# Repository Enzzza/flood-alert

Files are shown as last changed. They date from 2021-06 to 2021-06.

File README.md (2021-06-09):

## _Flood detection system_
 
Last winter we almost had a problem when the autumn leaves clogged the drain, luckily I reacted on time. That's why i decided to build flood alert system that would notify me over WiFi if there is flood detection.

Parts needed: 

- Esp32 Microcontroller 
- PP Float Switch
- Active Buzzer
- Leds
- 220Ω Resistors
- Cables
<br>
<br>

<br>

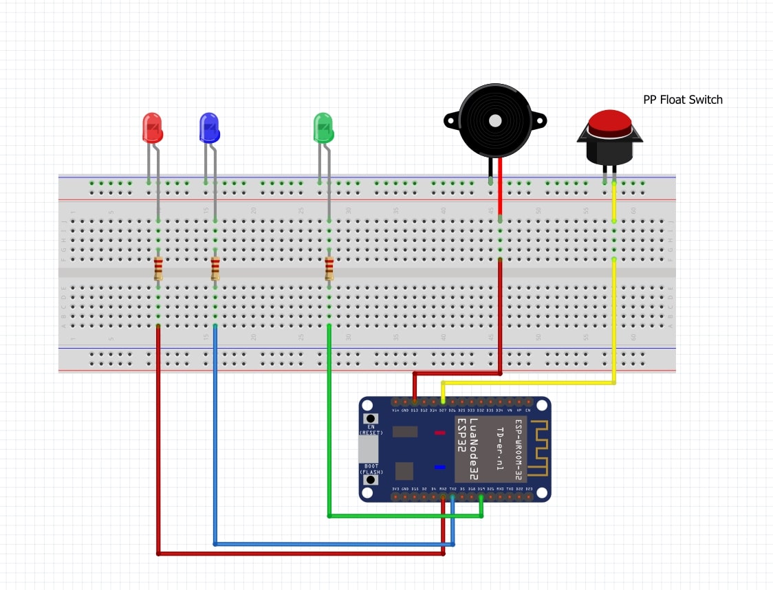
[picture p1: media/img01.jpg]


<p align = "left">
Basic schematic diagram
</p>

Idea behind this system is when PP Float Switch detect water rising it sends HIGH signal to ESP32 microcontroller. After ESP32 detects this signal it will send push notification over WiFi to the Blynk server, Blynk server will send notification to our device. Also ESP32 will play alarm sound  and it will turn on led lights. When ESP32 is not detecting flood it will indicate that with green led light.

<br>

Next step is to build prototype.
<br>

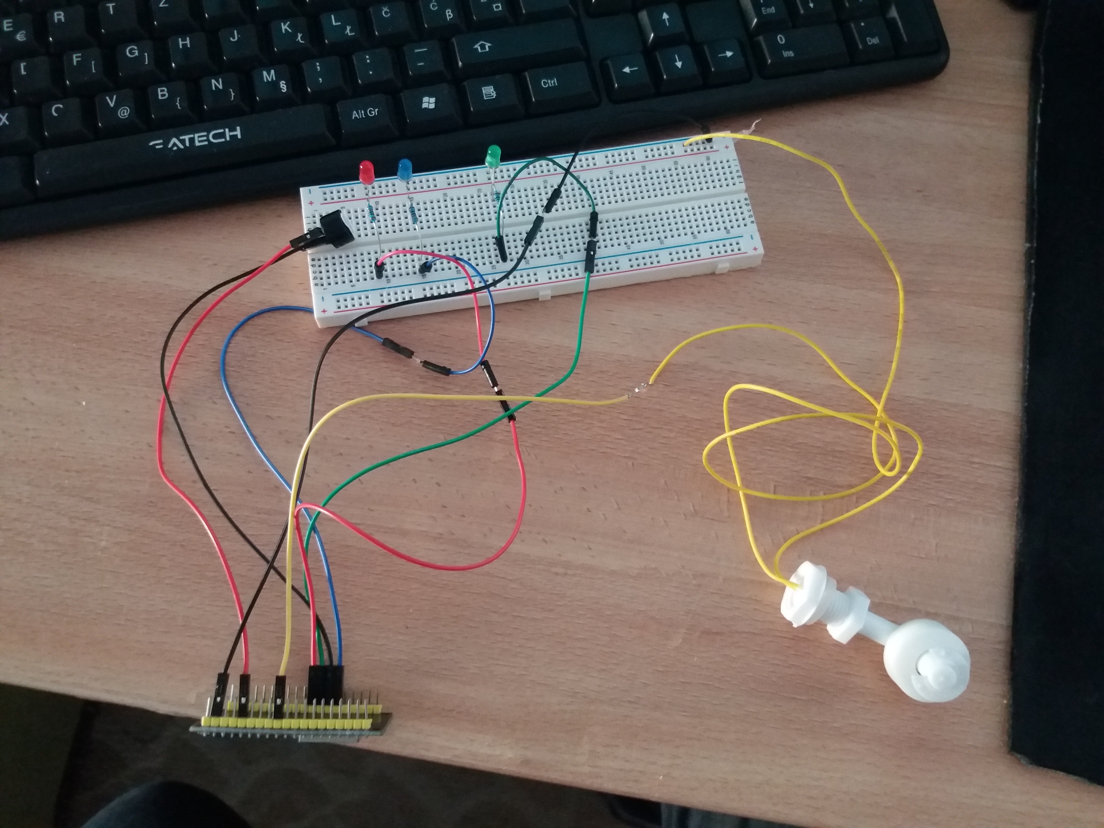
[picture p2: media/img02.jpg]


<p align = "left">
Prototype
</p>

<br>

Now we will put it all together. I will use IP55 enclosure box because this box won't be directly exposed to the rain. If your box will be exposed to rain use IP66, IP67 or IP68 type.

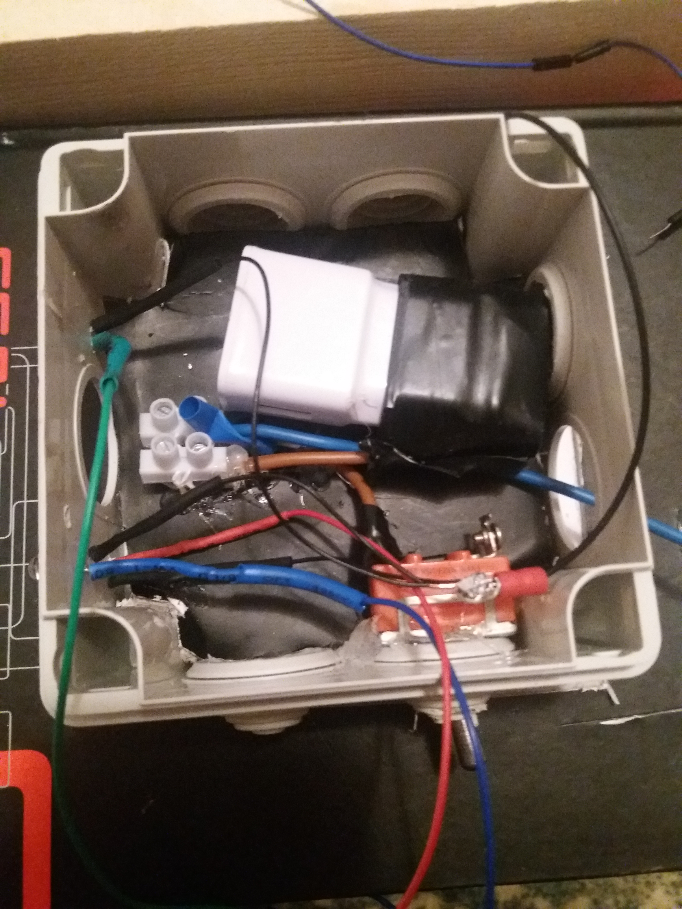
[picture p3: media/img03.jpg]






<br>
<br>

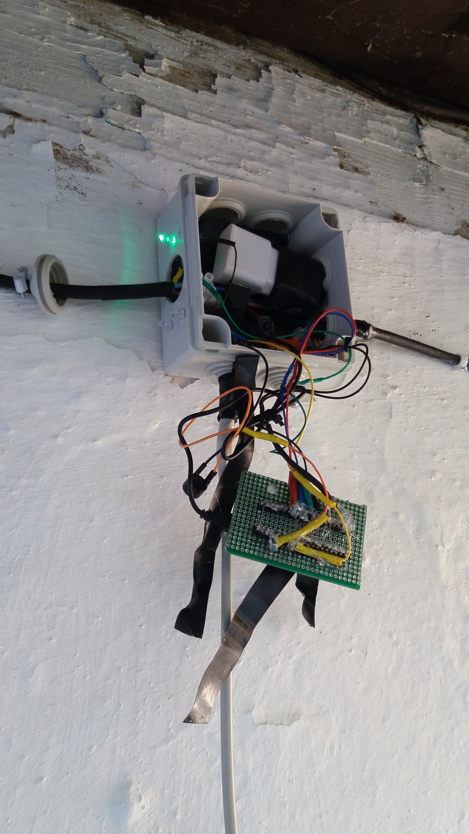
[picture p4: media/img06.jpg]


<p align = "left">
Mounting box on the wall
</p>



<p align = "left">
Mounting sensor to the bracket
</p>

After we finished hardware part of project now is time to setup [Blynk](https://docs.blynk.cc/) server.

Download Blynk App for your smartphone.

1. Create a Blynk Account
After you download the Blynk App, you’ll need to create a New Blynk account. This account is separate from the accounts used for the Blynk Forums, in case you already have one.

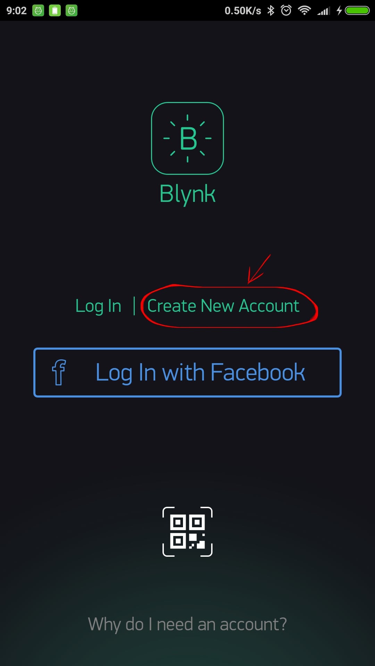
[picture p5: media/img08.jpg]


2. Create a New Project
After you’ve successfully logged into your account, start by creating a new project.

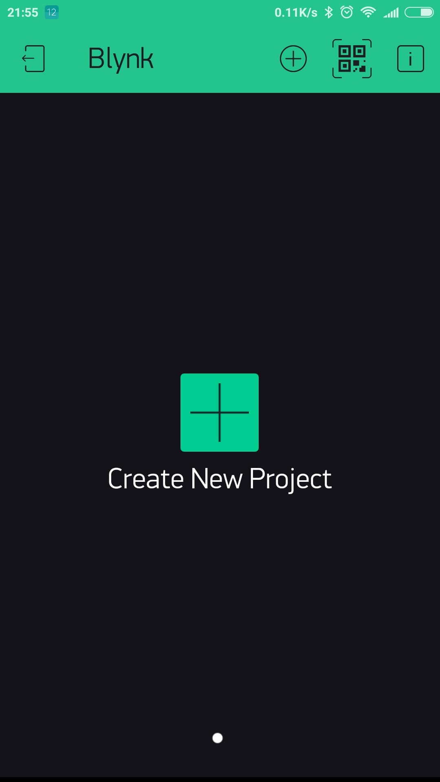
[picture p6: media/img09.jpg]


3. Choose Your Hardware
We will use Esp32

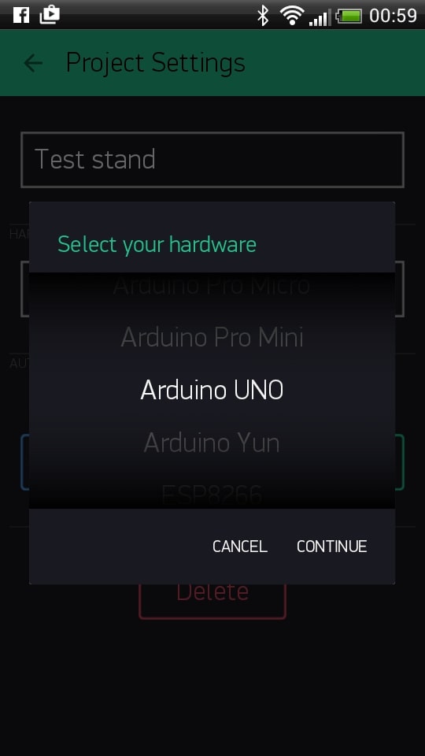
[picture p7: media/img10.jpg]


4. Auth Token
Auth Token is a unique identifier which is needed to connect your hardware to your smartphone. Every new project you create will have its own Auth Token. You’ll get Auth Token automatically on your email after project creation. You can also copy it manually. Click on devices section and selected required device :

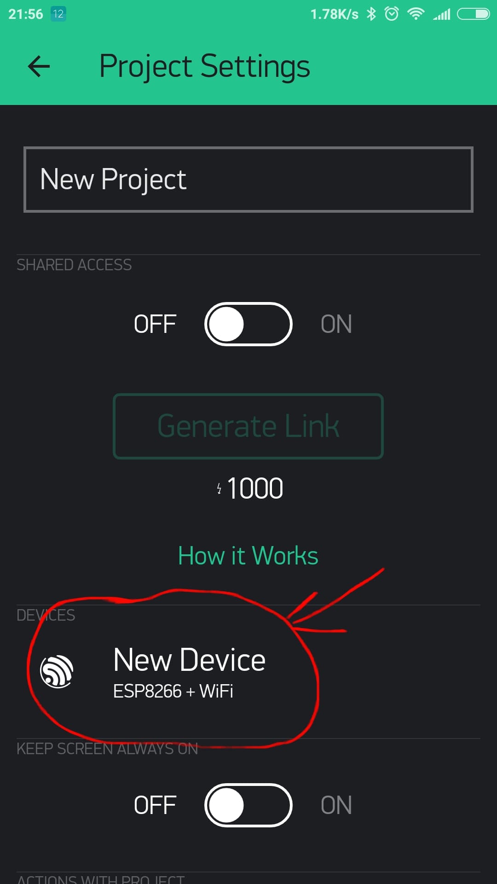
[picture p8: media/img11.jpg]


And you’ll see token :

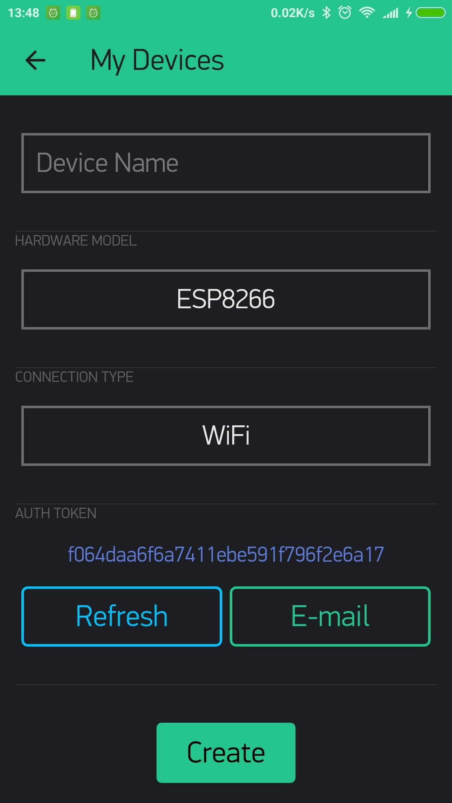
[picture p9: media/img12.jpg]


NOTE: Don’t share your Auth Token with anyone, unless you want someone to have access to your hardware.

Now press the “Create” button.

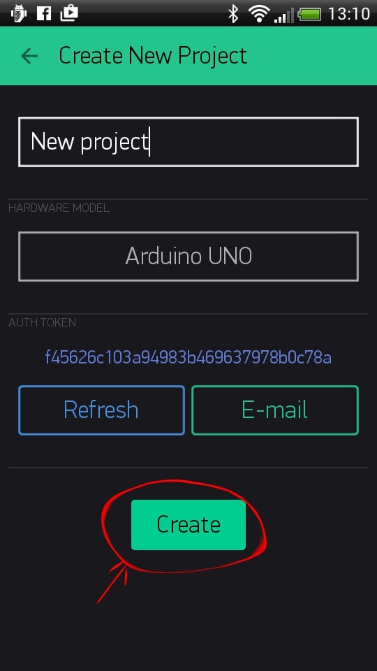
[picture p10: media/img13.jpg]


5. Add a Widget

We will use notification widget

Push Notification widget allows you to send push notification from your hardware to your device.
<br>
<br>
Example code:

```powershell
Blynk.notify("Hey, Blynkers! My hardware can push now!");
```

In esp32 folder there is config.h file copy token you got from step 4 into this file.

```powershell
char ssid[]            = "YOUR SSID";
char pass[]            = "YOUR PASSWORD";
char auth[]            = "YOUR BLYNK AUTH TOKEN";
char serveraddr[]      = "blynk-cloud.com";
unsigned int port      = 80;

// Uncomment this if you are hosting your blynk server  locally
//IPAddress serveraddr  (192,   168,   0,   55); // local server ip 
//unsigned int port      = 1234; // port of your local server

// Static IP
IPAddress esp32_ip ( 192,  168,   0,  100);
IPAddress gateway_ip ( 192,  168,   0,   1);
IPAddress subnet_mask(255, 255, 255,     0);
IPAddress primary_DNS(8, 8, 8, 8);   //optional
IPAddress secondary_DNS(8, 8, 4, 4); //optional

```

Now we can recive push notifications on our smartphone.

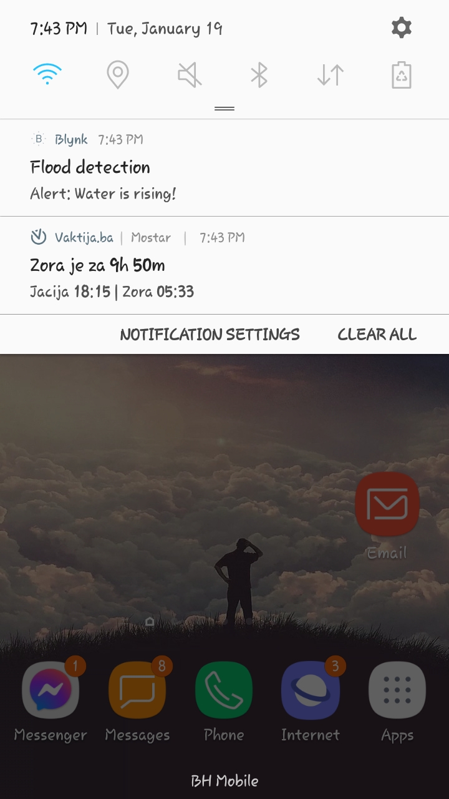
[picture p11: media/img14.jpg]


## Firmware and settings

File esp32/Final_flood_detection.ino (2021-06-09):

#define RED_PIN 16
#define GREEN_LED 19
#define BLUE_PIN 17
#define BUZZER_PIN 13
#define FLOAT_PIN 27

#define ESP32_HOSTNAME "FloodDetectionAlarm"
#define BLYNK_TIMEOUT_MS  500
#define BLYNK_HEARTBEAT   17
#define BLYNK_PRINT Serial
#include <WiFi.h>
#include <BlynkSimpleEsp32.h>
#include "config.h"

bool isDeviceOnline = false;

class Flasher
{
    // Class Member Variables
    // These are initialized at startup
    int ledPin;      // the number of the LED pin
    long OnTime;     // milliseconds of on-time
    long OffTime;    // milliseconds of off-time

    // These maintain the current state
    int ledState;                 // ledState used to set the LED
    unsigned long previousMillis;   // will store last time LED was updated

    // Constructor - creates a Flasher
    // and initializes the member variables and state
  public:
    Flasher(int pin, long on, long off)
    {
      ledPin = pin;
      pinMode(ledPin, OUTPUT);

      OnTime = on;
      OffTime = off;

      ledState = LOW;
      previousMillis = 0;
    }

    void Update()
    {
      // check to see if it's time to change the state of the LED
      unsigned long currentMillis = millis();

      if ((ledState == HIGH) && (currentMillis - previousMillis >= OnTime))
      {
        ledState = LOW;  // Turn it off
        previousMillis = currentMillis;  // Remember the time
        digitalWrite(ledPin, ledState);  // Update the actual LED
      }
      else if ((ledState == LOW) && (currentMillis - previousMillis >= OffTime))
      {
        ledState = HIGH;  // turn it on
        previousMillis = currentMillis;   // Remember the time
        digitalWrite(ledPin, ledState);   // Update the actual LED
      }
    }

    void setOnTime(int on) {
      OnTime = on;
    }

    void setOffTime(int off) {
      OffTime = off;
    }

    void Stop() {
      digitalWrite(ledPin, LOW);
    }
};

class Alarm
{
    Flasher _redLed;
    Flasher _blueLed;


    int _redPin;
    int _bluePin;
    int _buzzerPin;


    static const int _maxNumOfEvents{10};
    static const int _delayTime{10};

    int _sentEvents;
    unsigned long _timeOfLastSentEvent;


    int _buzzerFreq;
    const static int _buzzerChannel {0};
    const static int _buzzerResolution {8};


  public:


    Alarm(int redPin, int bluePin, int buzzerPin):
      _redLed(redPin, 200, 200),
      _blueLed(bluePin, 400, 400){


      _buzzerPin = buzzerPin;
      _redPin = redPin;
      _bluePin = bluePin;

      _sentEvents = 0;
      _timeOfLastSentEvent = 0;

      _buzzerFreq = 2000;
      ledcSetup(_buzzerChannel, _buzzerFreq, _buzzerResolution);
      ledcAttachPin(_buzzerPin, _buzzerChannel);

    }

    void turnOnLeds() {
      _redLed.Update();
      _blueLed.Update();
    }

    void turnOffLeds() {
      _redLed.Stop();
      _blueLed.Stop();
    }

    void sendEvent() {
      unsigned long currentMillis = millis();
      unsigned long timePassed = currentMillis - _timeOfLastSentEvent;
      if (_sentEvents == 0) {
        Blynk.notify("Alert: Water is rising!");
        _sentEvents++;
        _timeOfLastSentEvent = currentMillis;
        Serial.println("Water is rising");
      }
      else if (timePassed  > (_delayTime * 6 * 1000) &&  _sentEvents < _maxNumOfEvents) {
        Blynk.notify("Alert: Water is rising!");
        _sentEvents++;
        _timeOfLastSentEvent = currentMillis;
        Serial.println("Water is rising");
      }

    }

    void turnOnBuzzer() {
      ledcWriteTone(_buzzerChannel, 2000);
    }

    void turnOffBuzzer() {
      ledcWriteTone(_buzzerChannel, LOW);
    }

    void runAlarm() {
      turnOnLeds();
      turnOnBuzzer();
      if (isDeviceOnline == true) {
        sendEvent();
      }

    }

    void stopAlarm() {
      _sentEvents = 0;
      turnOffLeds();
      turnOffBuzzer();
    }

};

BlynkTimer timer;
volatile bool isFlooding = false;



portMUX_TYPE synch = portMUX_INITIALIZER_UNLOCKED;
#define DEBOUNCE_TIME 250
volatile uint32_t DebounceTimer = 0;

void IRAM_ATTR detectsFlooding() {
  portENTER_CRITICAL(&synch);

  if (millis() - DEBOUNCE_TIME >= DebounceTimer) {
    DebounceTimer = millis();
    isFlooding = true;

    Serial.println("FLOOD DETECTED!!!");
    digitalWrite(GREEN_LED, LOW);
  }

  portEXIT_CRITICAL(&synch);
}

Alarm alarmer(RED_PIN, BLUE_PIN, BUZZER_PIN);
int alarmTimerID = -2;
int loopTimerID = -3;


void setup()
{
  Serial.begin(115200);
  Serial.println();
  WiFi.setHostname(ESP32_HOSTNAME);
  WiFi.mode(WIFI_STA);
  Blynk.config(auth);
  CheckConnection();
  timer.setInterval(15000L, CheckConnection);

  pinMode(FLOAT_PIN, INPUT_PULLUP);
  attachInterrupt(digitalPinToInterrupt(FLOAT_PIN), detectsFlooding, FALLING);
  loopTimerID = timer.setInterval(1000L, floodAlertOn);


  pinMode(GREEN_LED, OUTPUT);
  digitalWrite(GREEN_LED, HIGH);
}

void loop()
{
  if (Blynk.connected()) {
    Blynk.run();
  }
  timer.run();
}


void floodAlertOn() {
  if (alarmTimerID == -2) {
    alarmTimerID = timer.setInterval(50L, alarmCallback);
    if (timer.isEnabled(alarmTimerID)) {
      timer.disable(alarmTimerID);
    }
  }

  if (isFlooding == true) {
    timer.enable(alarmTimerID);
    timer.disable(loopTimerID);
  }


}

void alarmCallback() {
  int state = digitalRead(FLOAT_PIN);
  if (state == 0) {
    isFlooding = true;
  } else {
    isFlooding = false;
  }

  if (isFlooding == false) {
    timer.disable(alarmTimerID);
    timer.enable(loopTimerID);
    alarmer.stopAlarm();
    digitalWrite(GREEN_LED, HIGH);
  } else {
    alarmer.runAlarm();
  }

}


void CheckConnection() {
  if (!Blynk.connected()) {
    isDeviceOnline = false;
    yield();
    if (WiFi.status() != WL_CONNECTED)
    {
      Serial.println("Not connected to WiFi! Connecting...");

      // Configures static IP address
      if (!WiFi.config(esp32_ip, gateway_ip, subnet_mask, primary_DNS, secondary_DNS)) {
        Serial.println("Static IP Failed to configure");
      }

      WiFi.begin(ssid, pass);
      delay(400); //give it some time to connect
      if (WiFi.status() != WL_CONNECTED)
      {
        Serial.println("Can't connect to WiFi!");
        isDeviceOnline = false;
      }
      else
      {
        Serial.println("Connected to WiFi!");
      }
    }

    if ( WiFi.status() == WL_CONNECTED && !Blynk.connected() )
    {
      Serial.println("Not connected to Blynk Server! Connecting...");
      Blynk.connect(); // It has 3 attempts of the defined BLYNK_TIMEOUT_MS to connect to the server, otherwise it goes to the next line
      if (!Blynk.connected()) {
        Serial.println("Connection failed!");
        isDeviceOnline = false;
      }
      else
      {
        isDeviceOnline = true;
      }
    }
  }
  else {
    Serial.println("Connected to Blynk server!");
    isDeviceOnline = true;
  }
}
